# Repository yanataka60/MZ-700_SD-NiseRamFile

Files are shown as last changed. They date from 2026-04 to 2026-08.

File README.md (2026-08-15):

# MZ-700_SD+偽RAMFILE複合ボード

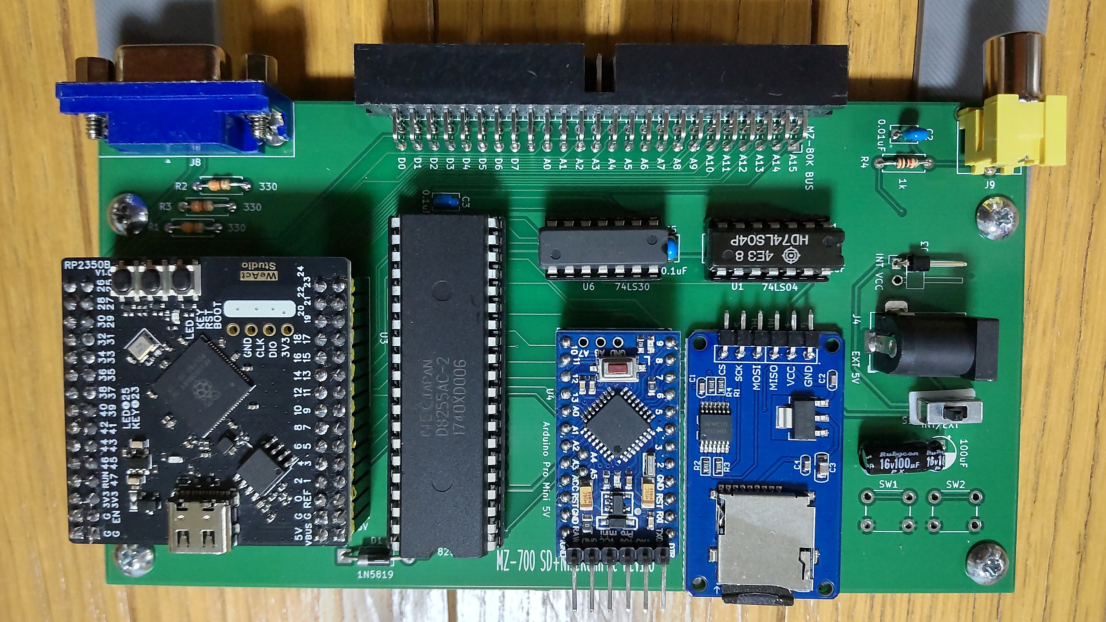
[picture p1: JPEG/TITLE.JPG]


　しっぽいいんちょさんが作られた「偽RAMFILE for MZ-1500」を元にしてMZ-700_SDを合体させたボードです。

　オマケとしてMZ-1500のサウンド機能を付加してMZ-1500用ゲームのサウンドも鳴るようにしてみました。あくまでオマケですので完全にMZ-1500と同等になるかは未検証です。

#### 2026.4.17 Rev1.2の回路中LPFのコンデンサの位置に誤りがありました。後述「Rev1.2回路の修正」によりコンデンサの位置を修正してください。

#### 2026.4.25 Rev1.5以降では回路・基板改善しています。Rev1.2基板の場合のみ、後述「Rev1.2回路の修正」によりコンデンサの位置を修正してください。

#### 2026.6.21 MZ-700_SD+偽RAMFILE複合ボードに電源が供給されている状態でUSB-Cケーブルを接続してはいけない問題に対してRev1.6基板ではすーぱーたーぼさんからご指摘いただいた対策を施しました。Rev1.2、Rev1.5基板でも通常の使用でMZ-700_SD+偽RAMFILE複合ボードに電源が供給されている状態でUSB-Cケーブルを接続することはありませんので通常使用においてRev1.2、Rev1.5基板でも問題ありません。

　以下の機能があります。

・MZ-700_SDの起動及びMZ-700_SDの機能

・EMM0からの起動(ただし、EMM0にHu-BASICの起動ディスクイメージがある場合のみ)

・EMM0エミュレータ(320KByte)

・漢字ROMボードエミュレータ

・MZ-700のテキスト出力をエミュレートしてVGA出力

・VGA出力される出力にMZ-1500相当のPCG機能、パレット機能

・VGA出力される出力にPCG-700相当のPCG機能

・MZ-1500相当のサウンドエミュレート(SN76489x2、8253)

・EXT-ROM領域(E800h～FFFFh)のRAM化(起動時にはF000h～FFFFhにMZ-700_SD用ROMの内容が自動的に書き込まれます。1Z-009B_LauncherをLOAD起動後であればEXT-ROMをファイル化したEXT-ROM.MZTをEXT-ROM領域にLOADが可能です)

MZ-700_SD: https://github.com/yanataka60/MZ-700_SD

　「偽RAMFILE for MZ-1500」にはMZ-1R12 SRAMメモリエミュレータの機能がありますが、MZ-700_SDの起動用に使用しているのでMZ-1R12 SRAMメモリエミュレータとしての機能は使用できません。

　なおこの基板は、しっぽいいんちょさんの「偽1500 for MZ-700」のnise1500.uf2を書き込めば「偽1500 for MZ-700」になります。

　「偽1500 for MZ-700」とはフラッシュROMの使い方が違いますのでuf2ファイルを書き込んだときはそれぞれの説明に従ったフラッシュROMへの書込みを行ってください。

偽1500 for MZ-700:https://github.com/shippoiincho/nise1500

### (2026.8.13追記)すねいるさんのBARYONに対応するためArduinoプログラムを更新しました。また、ROMプログラムも合わせて更新することで多段ロードにも対応します。

### 多段ロードの詳細についてはMZ-80K_SDの「BARYON対応」「多段ロード対応」を参照してください。

　BARYON対応:https://github.com/yanataka60/MZ80K_SD#baryon%E5%AF%BE%E5%BF%9C2026813

　多段ロード対応:https://github.com/yanataka60/MZ80K_SD#%E5%A4%9A%E6%AE%B5%E3%83%AD%E3%83%BC%E3%83%89%E5%AF%BE%E5%BF%9C2026813

　Arduinoプログラム、ROMプログラムともMZ-80K_SD用に更新したものがそのまま使えます。

### BARYON起動時にE800h以降にも書き込み動作を行うようです。MZ-80K_SD、MZ-700_SDでは問題ありませんが、MZ-700_SD+偽RAMFILE複合ボードではE800h以降もRAM扱いとしていたため、SDアクセスルーチンが破壊されてしまいます。

### 当面、E800h以降はROM扱いに変更しましたのでRP2350Bフォルダにあるniseramfile.uf2でRP2350Bマイコンボードを書き換えてください。

## 回路図
　KiCadフォルダ内のMZ-700_SD+NRF.pdfを参照してください。

[回路図](https://github.com/yanataka60/MZ-700_SD-NiseRamFile/blob/main/KiCad/MZ-700_SD%2BNRF.pdf)

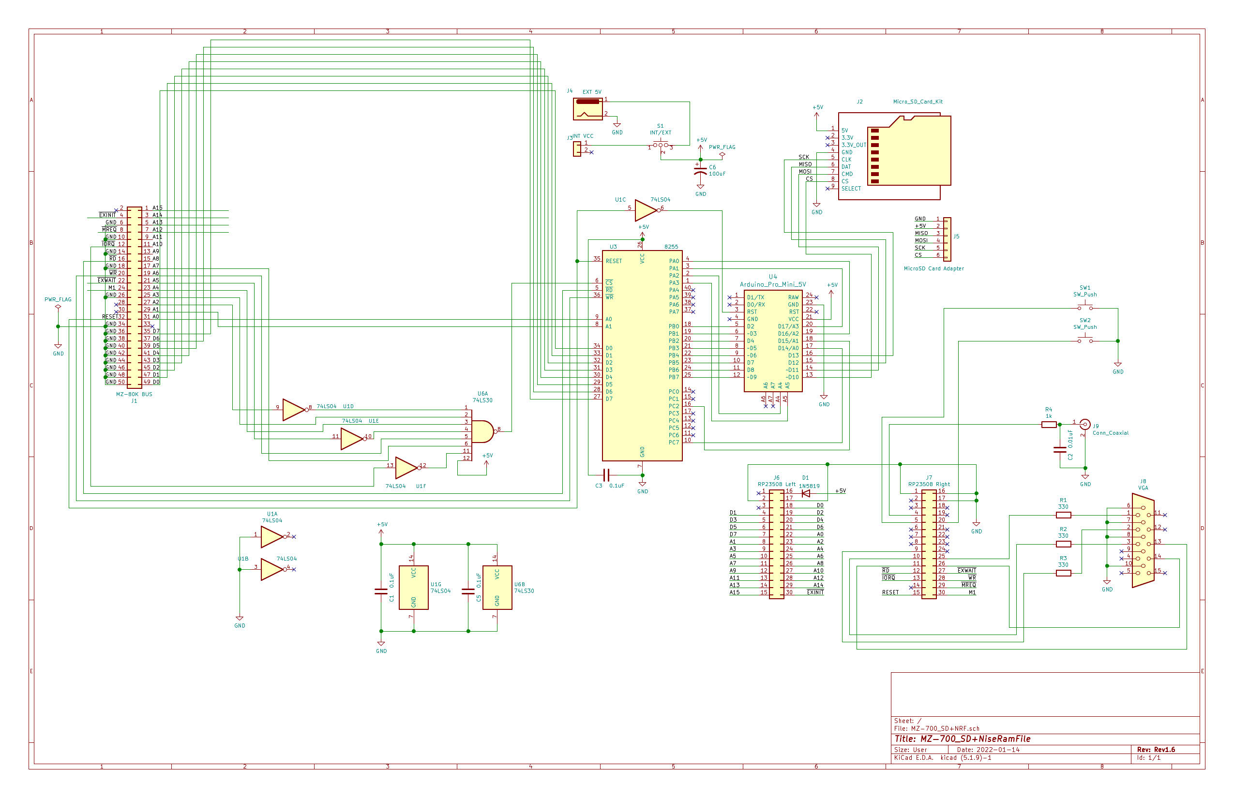
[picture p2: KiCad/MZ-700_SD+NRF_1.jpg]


|番号|品名|数量|備考|
| --- | --- | --- | --- |
||J2、J5のいずれか|||
|J2|Micro_SD_Card_Kit|1|秋月電子通商 AE-microSD-LLCNV (注2)|
|J5|MicroSD Card Adapter|1|Arduino等に使われる5V電源に対応したもの(注4)|
|J3|コネクタ 2Pin|1|ピンヘッダで代用するときはGNDと間違えないよう1Pinで5Vだけにしたほうが良い|
|J4|DCジャック|1||
|J6,J7|ピンソケット2x15Pin|2|RP2350Bマイコンボード用,秋月電子通商 FHU-2x42SGなど|
|J8|VGA用基板ソケット 3列15ピン|1|マルツ DJ-VGA14.5など (注1)|
|J9|RCAジャック|1|秋月電子通商 MJ-523など|
|S1|3Pスライドスイッチ|1|秋月電子通商 SS12D01G4など|
|U1|74LS04|1||
|U3|8255|1||
|U4|Arduino_Pro_Mini_5V|1|Atmega328版を使用 168版は不可。(注3)|
|U6|74LS30|1||
||RP2350Bボード(Raspberry Pi Pico 2)|1|Amazon WA00021 RP2350Bマイコンボードなど|
|C1,C3,C5|積層セラミックコンデンサ 0.1uF|3||
|C2|積層セラミックコンデンサ 0.01uF|1||
|C6|電解コンデンサ 16v100uF|1||
|D1|ダイオード 1N5819|1||
|R1-R3|カーボン抵抗 330Ω|3||
|R4|カーボン抵抗 1kΩ|1||
||ピンヘッダ|2Pin分|Arduino_Pro_MiniにはA4、A5用のピンヘッダが付いていないため別途調達が必要です 秋月電子通商 PH-1x40SGなど|
||ピンソケット(任意)|26Pin分|Arduino_Pro_Miniを取り外し可能としたい場合に調達します 秋月電子通商 FHU-1x42SGなど|

　　　注1)VGA用基板ソケットには、ピン間隔の異なるものがあるようです。マルツ DJ-VGA14.5ではないものを購入する場合はこちらで寸法を確認してください。

　　　https://www.marutsu.co.jp/contents/shop/marutsu/datasheet/DJ-VGA14.5.pdf

　　　注2)秋月電子通商　AE-microSD-LLCNVのJ1ジャンパはショートしてください。

　　　注3)Arduino Pro MiniはA4、A5ピンも使っています。

　　　注4)MicroSD Card Adapterを使う場合

　　　　　J6に取り付けます。

　MicroSD Card Adapterについているピンヘッダを除去してハンダ付けするのが一番確実ですが、J6の穴にMicroSD Card Adapterをぴったりと押しつけ、裏から多めにハンダを流し込むことでハンダ付けをする方法もあります。なお、この方法の時にはしっかりハンダ付けが出来たかテスターで導通を確認しておいた方が安心です。

　ハンダ付けに自信のない方はJ5の秋月電子通商　AE-microSD-LLCNVをお使いください。AE-microSD-LLCNVならパワーLED、アクセスLEDが付いています。

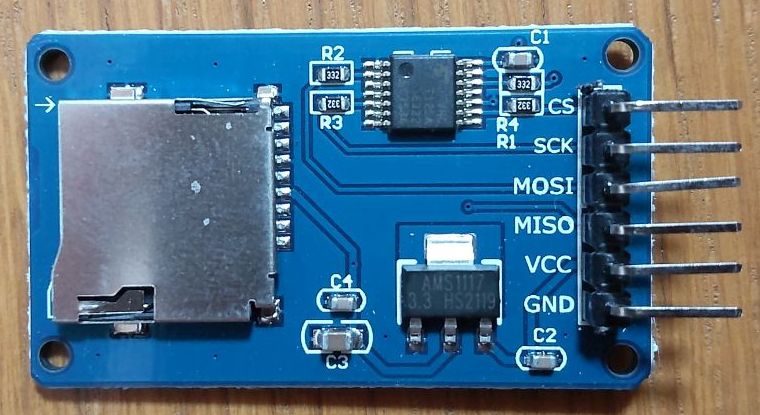
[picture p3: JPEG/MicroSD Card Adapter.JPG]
MicroSD Card Adapter1


## Rev1.2回路の修正(Rev1.2のみ、Rev1.5以降では修正しています)
　Rev1.2の回路に誤りがありました。LPF用コンデンサ(C2)を取り外し、0.01uFに変更の上、基板ハンダ面よりR4の出力側になるように取り付けてください。

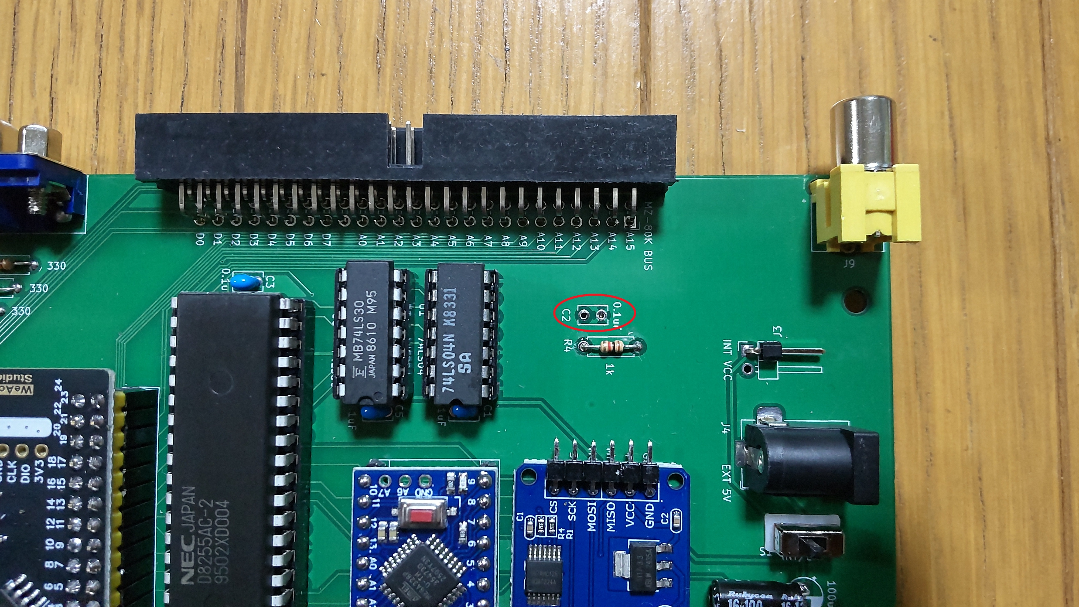
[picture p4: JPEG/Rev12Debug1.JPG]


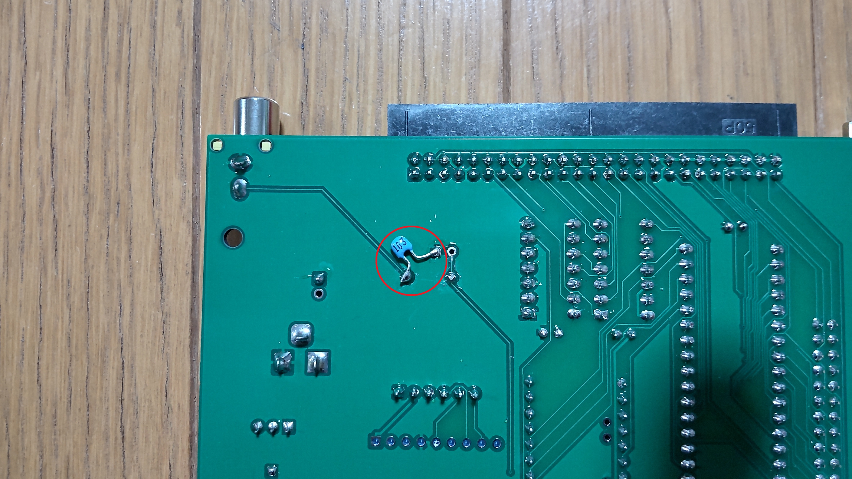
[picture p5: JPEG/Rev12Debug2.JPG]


## 偽RAMFILE for MZ-700の書込み
　RP2350Bフォルダにあるniseramfile.uf2をRP2350Bマイコンボードに書き込みます。

　RP2350BのBOOTボタンを押しながらUSB-Cケーブルを接続するとパソコンがUSBメディアとして認識しますのでniseramfile.uf2をドロップすると自動的に書き込まれます。

　書き込みが終了するとパソコンからはUSBとして見えなくなりますのでそうなったらケーブルを抜いて終了です。

### 書き込み(USB-Cケーブル接続)時の注意
#### Rev1.2基板、Rev1.5基板
　USB-Cケーブルを接続するときは、USB-C以外からMZ-700_SD+偽RAMFILE複合ボードに電源が供給されないようにしてください。

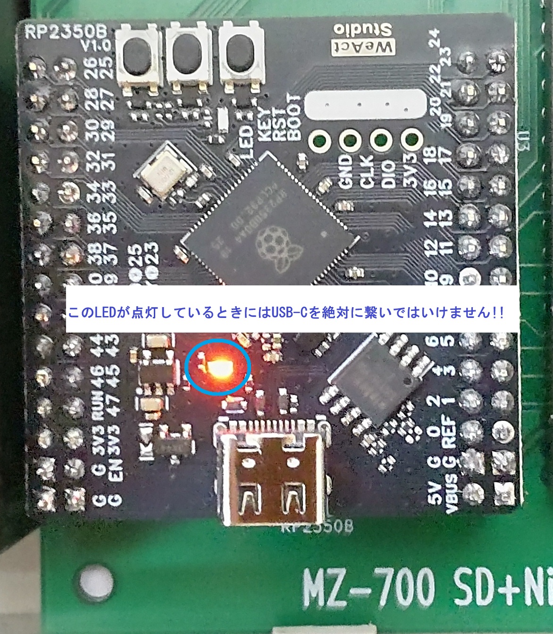
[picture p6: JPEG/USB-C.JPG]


　MZ-700内部から内部電源として供給しているならMZ-700の電源は必ず切っておく、ACアダプタから外部電源として供給しているなら電源ジャックから外しておいてください。

　また、書き込み終わったらUSB-Cは必ず外してください。

#### Rev1.6基板
　対策済みです。USB-Cケーブルを接続するときにUSB-C以外からMZ-700_SD+偽RAMFILE複合ボードに電源が供給されていても問題は無くなっていますが、書き込むときにはUSB-Cケーブル以外から電源が供給されていない状態で行う方が無難です。

## MZ-700_SD用ROMプログラムの書き込み
~~MZ-700_SD/EMMフォルダ内のFD_rom1.bin又はFD_rom.binをRP2350BのフラッシュROMへ書き込みます。~~

~~https://github.com/yanataka60/MZ-700_SD/blob/main/EMM/FD_rom.BIN~~

(2026.8.13)多段ロード対応に伴い、MZ-80K_SDに統合しました。MZ-80K_SD/Z80フォルダ内のFD_rom.BINを使ってください。

https://github.com/yanataka60/MZ80K_SD/blob/main/Z80/FD_rom.BIN

　書き込みにはpicotool.exeが必要となります。以下のウェブページ右側の「Releases」からダウンロードできます。

https://github.com/raspberrypi/pico-sdk-tools

```
picotool.exe load -v -x FD_rom1.bin  -t bin -o 0x10080000
```

　また、EMM0に起動可能な内容(HuBASIC起動イメージ)があればEMMからの起動が可能です。

　EMMの内容をチェックしていないのでEMMが起動可能な内容(HuBASIC起動イメージ)でなかった場合には暴走しますのでご注意ください。

　EMM0からの起動は、MONITORから「FDE0」コマンドで起動できます。

## FONTファイルの書込み
　VGA出力を有効とするためにはMZ-700のフォントをRP2350Bに書き込む必要があります。

　MZ-700はソフトウェア的にフォントを取り出すすべがありませんが、疑似的に作り出す又はソフトウェアで読み出せるMZ-1500のFONTを使うなどの方法があります。Webで検索して作成してください。

　書き込みはpicotoolを使います。

```
picotool.exe load -v -x font.rom  -t bin -o 0x1001f000
```

## Arduinoプログラム
　MZ-80K_SDを参照してください。

https://github.com/yanataka60/MZ80K_SD?tab=readme-ov-file#arduino%E3%83%97%E3%83%AD%E3%82%B0%E3%83%A9%E3%83%A0

## 拡張機能の使い方
### MZ-700_SD(MZ-80K_SD)の起動
　MZ-700_SD(MZ-80K_SD)の起動方法、使用方法と同じです。

MZ-700_SD:https://github.com/yanataka60/MZ-700_SD

MZ-80K_SD:https://github.com/yanataka60/MZ80K_SD

### EMM0エミュレータ
　320KByteのEMM0として機能します。バッテリーバックアップ機能はなく、電源断で内容は消失します。

　ただし、バックアップ用のSlotが32個用意されているので電源断前にSlotに退避しておくことが可能です。

　また、Slot0の内容は電源投入又はIPL RESETした時にEMM0に自動的にコピーされるのであたかもバッテリーバックアップされていたかのような使い方が出来ます。

　EMMとSlotとのやり取りはI/Oポートから指示します。

#### SlotxxからEMM0への復帰
|アドレス|R/W|説明|
| --- | --- | --- |
|8Ch|W|指定したSlot番号(0～31)のSlotの内容をEMM0に復帰|

#### EMM0からSlotxxへの退避
|アドレス|R/W|説明|
| --- | --- | --- |
|8Dh|W|指定したSlot番号(0～31)のSlotへEMM0の内容を退避|

HuBASICからは以下のようになります。

```
OUT &H8C,0
```

```
OUT &H8D,0
```

　「EMM0」に起動可能なMZ-700用HuBASICが存在している場合、コマンド「FDE0」を実行することで「EMM0」のMZ-700用HuBASICから起動可能です。

　なお、EMMの00000番地が「01h」でなければEMMからの起動はせずにコマンド待ちに戻りますが、00000番地以降に異常があってもチェックはしていないので最悪暴走します。

　MZ-700用HuBASICは、テープ版しかなくそのままではEMMにHuBASICの起動イメージを作成することが出来ません。

　BouKiCHiさんのHuDiskなどを使いMZ-700用HuBASICの起動ディスクイメージを作成したうえでEMMMENUのEMMLOADでEMMに書き込む必要があります。

　EMMイメージを登録する場合はpicotoolから以下のようにします。

```
picotool.exe load -v -x EMM_image.bin  -t bin -o 0x10280000
```

### 漢字・辞書ROM MZ-1R13
　漢字・辞書ROM MZ-1R13から抽出したデータを登録します。

　抽出にはGET1R13を使いました。

http://fukui.s17.xrea.com/retro/mz2080b/mzgetkrom.html

　出来上がったファイルをpicotoolで登録します。

```
picotool.exe load -v -x MZ_1R13_DIC.ROM -t bin -o 0x10040000
```

```
picotool.exe load -v -x MZ_1R13.ROM  -t bin -o 0x10020000
```

## MZ-80K用ゲーム(アプリケーション)の実行
　FDL、FDコマンドでLOAD実行が可能です。アプリケーション内でのLOAD、SAVEには本体内ROMの書き換え、もしくはアプリケーションの書き換えが必要です。

　また、キーボードの違いによりそのまま動かないことがあります。

　詳しくは、MZ-80K_SDを参照してください。

https://github.com/yanataka60/MZ80K_SD

## MZ-700用ゲーム(アプリケーション)の実行
　FDL、FDコマンドでLOAD実行が可能です。アプリケーション内でのLOAD、SAVEにはアプリケーションを対応させる必要がある場合があります。

　詳しくは、MZ-80K_SDを参照してください。

https://github.com/yanataka60/MZ80K_SD

## MZ-1500用ゲーム(アプリケーション)の実行
　MZ-1500用ゲーム(アプリケーション)が動作するかもしれないのはあくまでもオマケです。動作したらラッキーぐらいでお願いします。

　なお、QD用ソフトは、事前にMZTファイル化しておいてください。

　また、アプリケーション内でLOAD、SAVEするにはMZ-1500_SDでアプリケーション内でのLOAD、SAVEに対応している必要があります。

　次の段階で試してみてください。

#### ①FDL、FDコマンドでLOAD実行。
　①で動いたもの

　　いぬふとさんのゲーム、PACKMAN、ICE BLOCK

#### ②多段LOADの場合は、FDL、FDコマンドでLOAD実行(PCG定義)。リセットして２段目をFDL、FDコマンドでLOAD実行(ゲーム本体)。
　②で動いたもの

　　DOORDOORmk2、FLAPPY、RALLY-X、ヴォルガード、DIGDUG、MAPPY、GALAGA、ドルアーガの塔(遊べますが外壁PCG定義が変です)

#### ③FDL、FDコマンドで1Z-009B_LauncherをLOAD実行し、1Z-009B_LauncherからFDL、FDコマンドでLOAD実行。
　③で動いたもの

　　サンダーフォース、BASIC MZ-5Z001(もしかしたら④の方が良いのかも)

#### ④FDL、FDコマンドで1Z-009B_LauncherをLOAD実行後、1Z-009B_LauncherからMZ-1500用EXT-ROM(E800h～FFFFh、実行アドレスE800h)をLOAD実行、MキーでMONITOR 9Z-502Mを起動したら「J0000」を実行して1Z-009B_Launcherに戻り、目的のアプリケーションをFDL、FDコマンドでLOAD実行。
　④で動いたもの

　　今のところ④が必要となったものには出会っていません。もしかしたらBASIC MZ-5Z001の機能のうち、EXT-ROMを必要とするものがあるかもしれません。

　　(2026.8.13追記)当面、E800h以降はROM扱いに変更しましたので④は使えなくなります。

### 1Z-009B_Launcherの作り方
　1Z-009B_Launcherフォルダにある1Z-009B_SD.mzt(2630Byte)の後ろにMZ-1500実機から抽出した1Z-009B MONITOR(0000h～0FFFh)をバイナリエディタなどで連結して保存してください。

　6627Byteのファイルになります。

　(2026.8.15追記)1Z-009B_Launcherも多段ロード対応にさせました。ただし今のところ1Z-009B_Launcherを使うのは③の場合のみですので使う場面はありません。

### MZ-1500用EXT-ROMファイルの作り方

(2026.8.15追記)E800h以降をROM扱いに変更しましたのでLOAD出来なくなりました。

　MZ-1500実機からEXT-ROM(E800h～FFFFh)までを抽出してバイナリファイルとしたうえでヘッダを付加してmztファイルとしてください。

　この時、実行アドレスをE800hとしておきます。

### MZ-700_SD+偽RAMFILE複合ボード対応BASIC MZ-5Z001
　前述「MZ-1500用ゲーム(アプリケーション)の実行」の③又は④でBASIC MZ-5Z001は実行可能ですが、SDを使用するにはSD用パッチあてが必要です。

　MZ-1500_SDとMZ-700_SDではArudinoをコントロールする8255のI/Oアドレスに違いがあり、MZ-1500_SD対応パッチを当てたBASIC MZ-5Z001はそのままでは使えないのでバイナリエディタで以下の修正を行ってください。

　「BASIC 1Z-5Z001-SD.MZT」(AUTORUN未対応版 42581Byte)
|MZTアドレス|修正前|修正後|
| --- | --- | --- |
|A30F|A3|DB|
|A313|A0|D8|
|A315|A2|DA|
|A31B|A1|D9|
|A320|A3|DB|
|A327|A3|DB|
|A33C|A0|D8|
|A340|A3|DB|
|A347|A3|DB|
|A34D|A2|DA|
|A354|A2|DA|

　「BASIC 1Z-5Z001-SD-AUTORUN.MZT」(AUTORUN対応版 42592Byte)
|MZTアドレス|修正前|修正後|
| --- | --- | --- |
|A31A|A3|DB|
|A31E|A0|D8|
|A320|A2|DA|
|A326|A1|D9|
|A32B|A3|DB|
|A332|A3|DB|
|A347|A0|D8|
|A34B|A3|DB|
|A352|A3|DB|
|A358|A2|DA|
|A35F|A2|DA|

## 専用トレイとカバー
　専用トレイとカバーを作ってみました。

　STLフォルダにあるSTLファイルを使ってください。

　トレイはCMTユニットを引っ掛ける手前のツメの下に潜り込ませるように入れます。

　カバーは手前からかぶせてツメに引っ掛けます。

　カバーを外すときは背面からトレイごと持ち上げるようにすると外れます。

　カバー内は、RP2350Bがギリギリ入る高さ16mmほどです。Arduino、SDカードユニットにソケットを使うときはその高さに収まる背の低いタイプを使ってください。

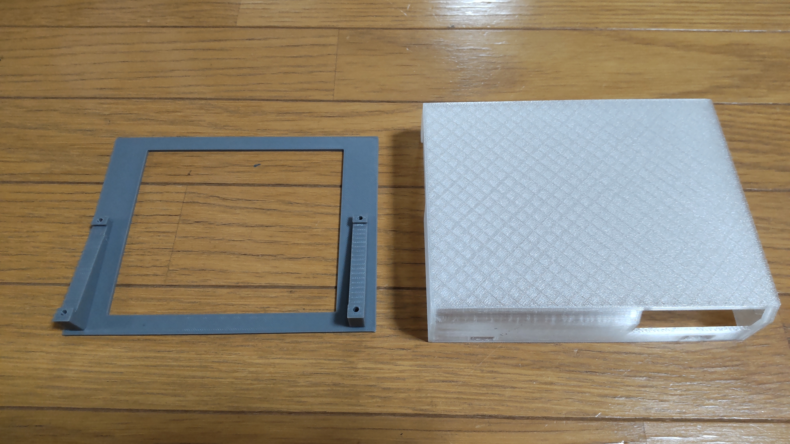
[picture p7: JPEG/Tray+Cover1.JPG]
Tray+Cover1


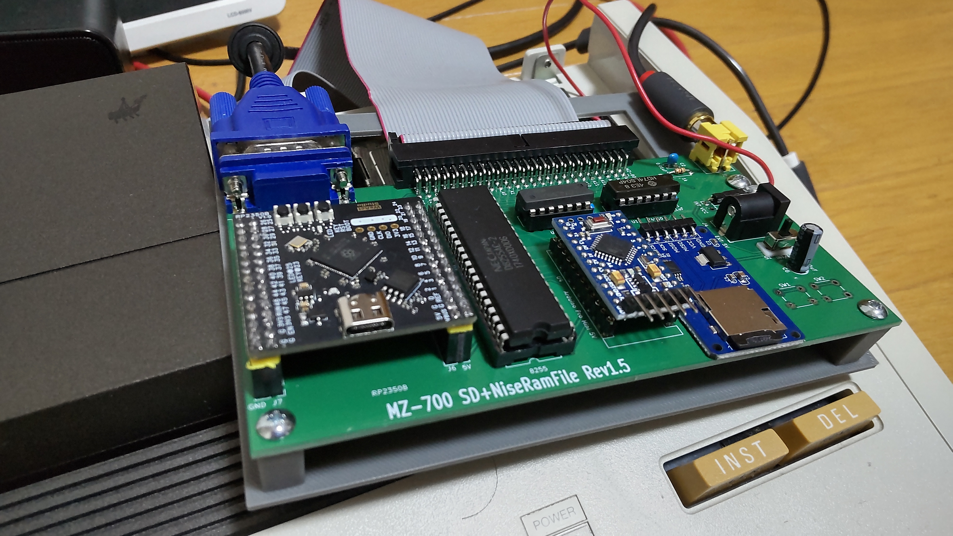
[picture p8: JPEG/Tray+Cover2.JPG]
Tray+Cover2


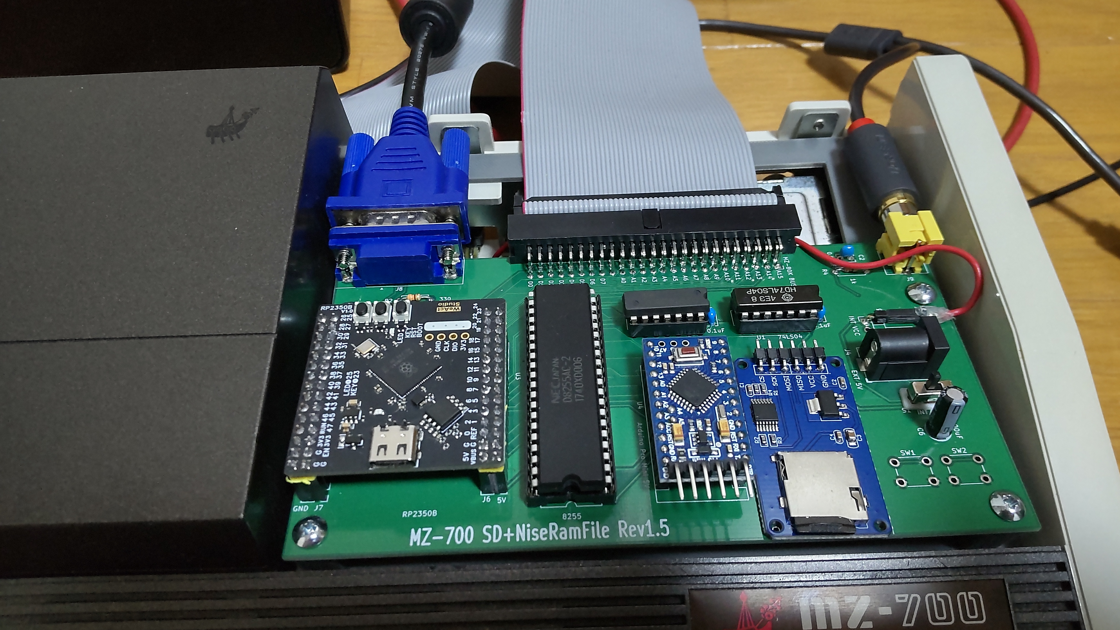
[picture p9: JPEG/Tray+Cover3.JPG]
Tray+Cover3


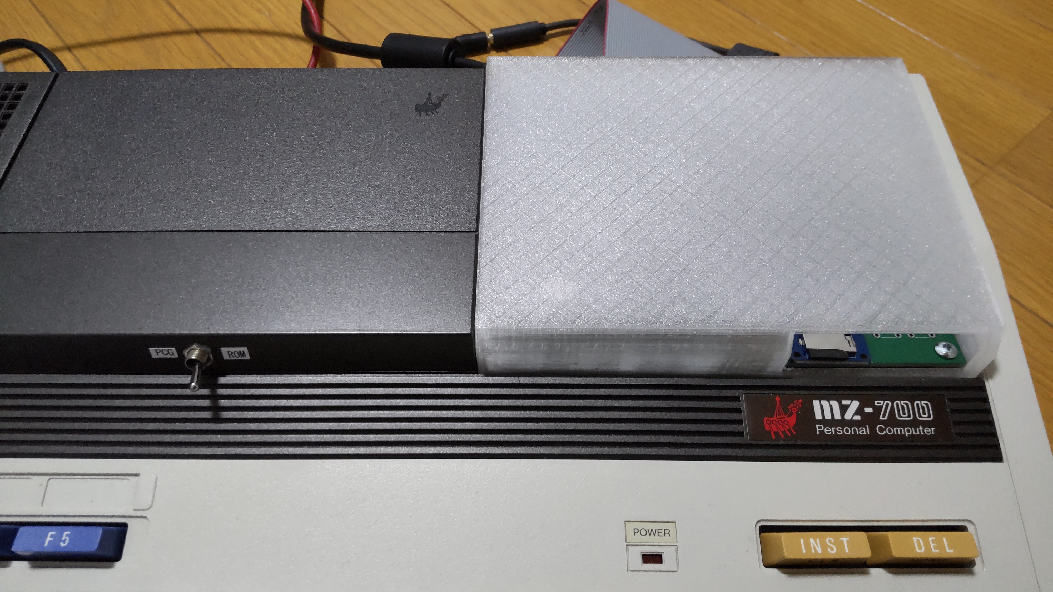
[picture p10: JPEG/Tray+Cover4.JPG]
Tray+Cover4


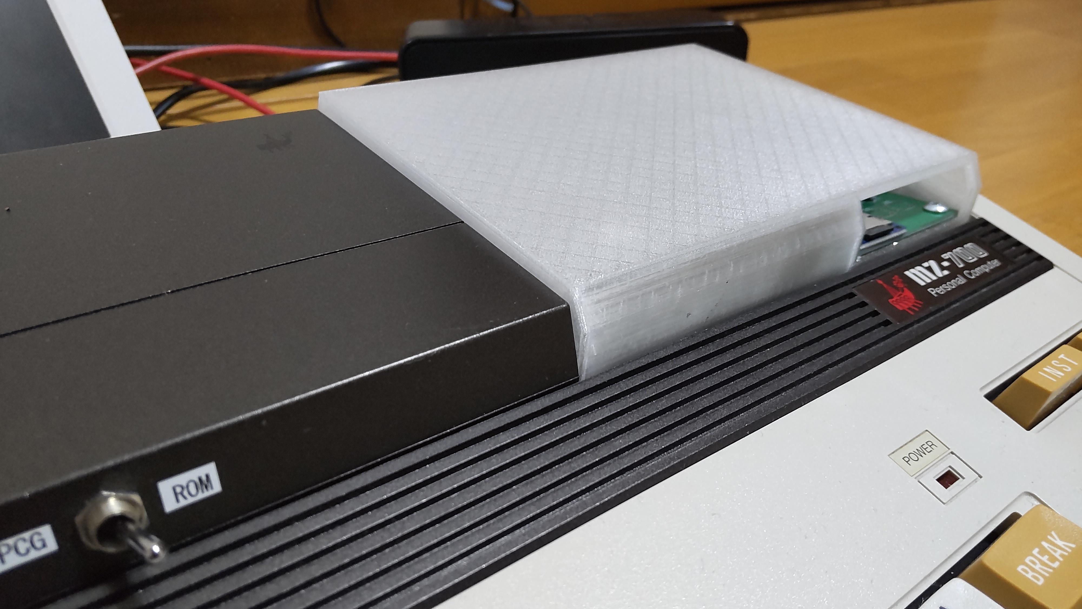
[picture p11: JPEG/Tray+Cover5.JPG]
Tray+Cover5


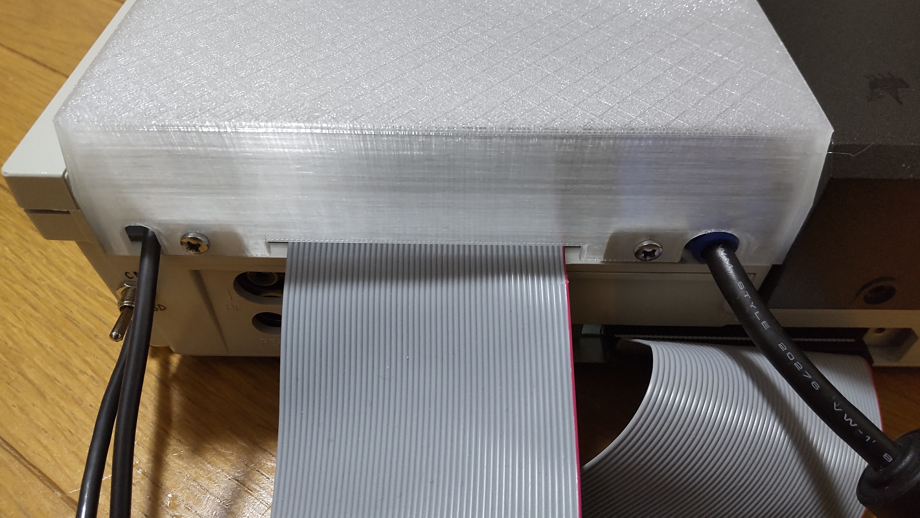
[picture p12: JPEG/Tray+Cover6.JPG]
Tray+Cover6


## 開発環境、使用ライブラリなど
　開発環境は、Visual Studio Codeです。

　VGAライブラリは以下を使用しています。

- [VGA ライブラリ(一部改変)](https://github.com/vha3/Hunter-Adams-RP2040-Demos/tree/master/VGA_Graphics)

## 謝辞
　素晴らしい拡張モジュールを開発し、自由に改変・公開を快く承諾してくださったしっぽいいんちょさん、ありがとうございました。

## 追記
2026.4.17 Rev1.2回路でLPFのコンデンサの位置に誤りがありました。すーぱーたーぼさん、ご指摘ありがとうございます。

2026.4.18 書き込み(USB-Cケーブル接続)時の注意を追記しました。

2026.4.25 Rev1.5を公開しました。

2026.4.30 トレイとカバーのSTLファイルを追加しました。
          MZ-700_SD+偽RAMFILE複合ボード対応BASIC MZ-5Z001にするための修正点を追記。

2026.6.21 MZ-700_SD+偽RAMFILE複合ボードに電源が供給されている状態でUSB-Cケーブルを接続してはいけない問題に対してすーぱーたーぼさんからご指摘いただいた対策を施しました。

2026.8.13 BARYONに対応しました。retrogamer128さんの要望により多段ロードに対応しました。

2026.8.15 1Z-009B_Launcherも多段ロード対応としました。

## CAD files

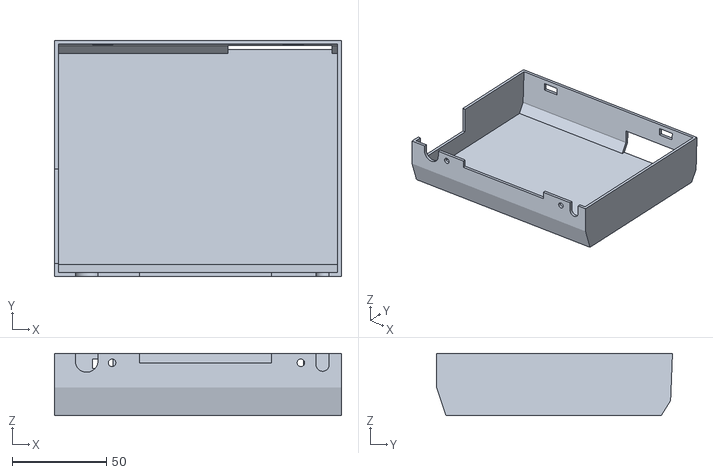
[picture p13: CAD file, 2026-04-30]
STL/MZ-700_SD+Nise_Cover.stl
152.0 x 125.0 x 33.0

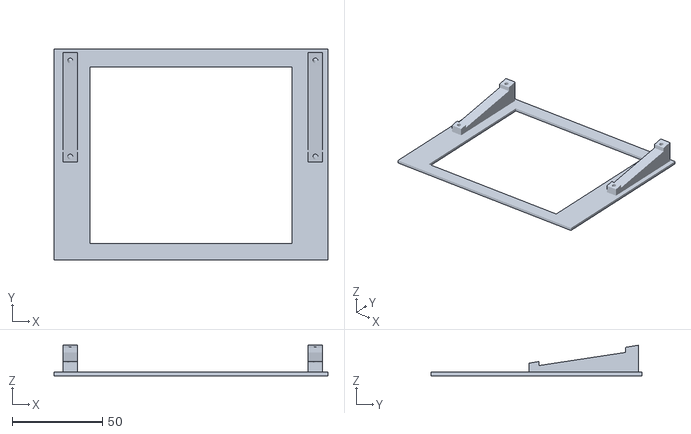
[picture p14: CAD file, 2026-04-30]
STL/MZ-700_SD+Nise_Tray.stl
152.0 x 117.0 x 17.0

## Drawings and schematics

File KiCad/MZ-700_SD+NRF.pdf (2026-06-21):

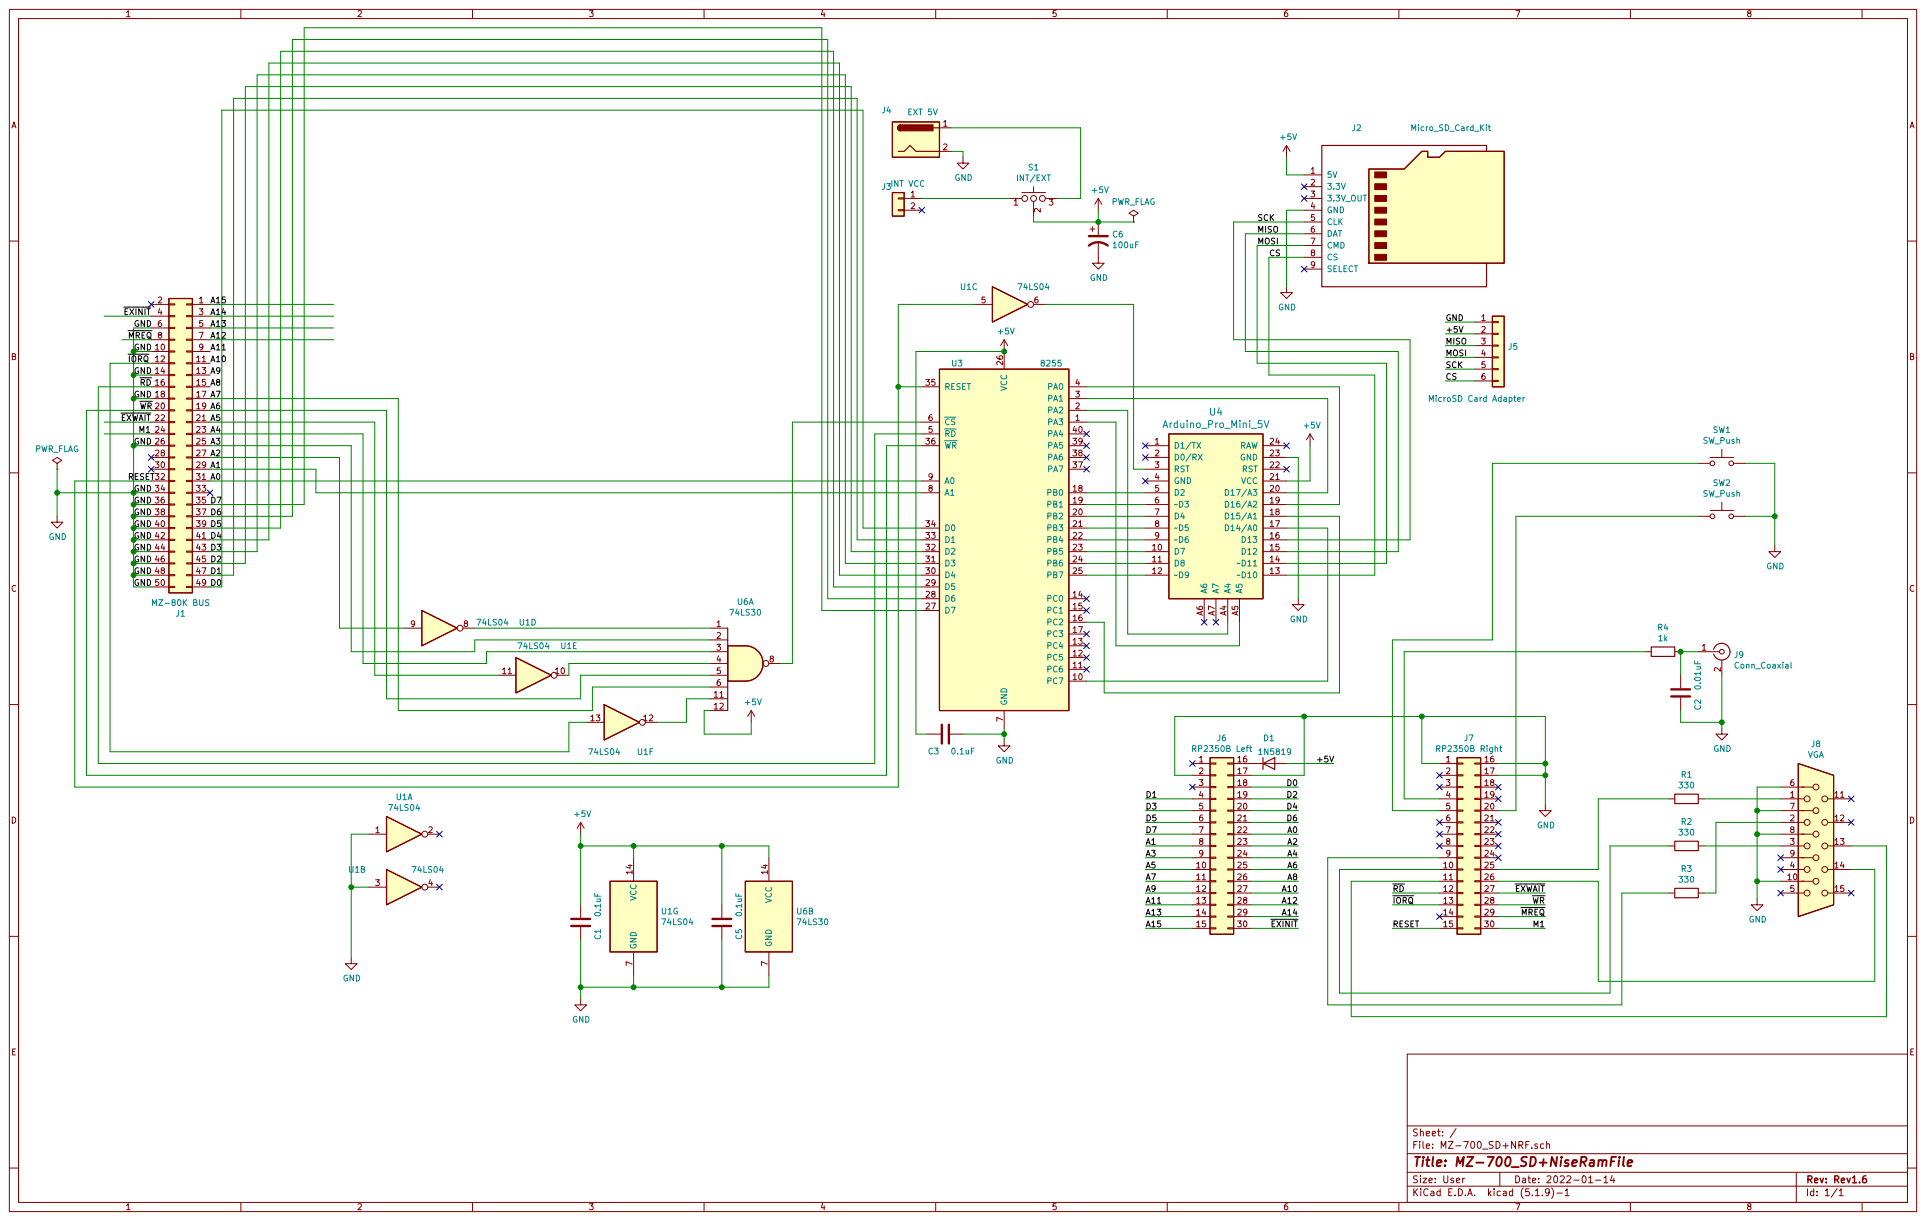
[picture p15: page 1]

EXINIT GND GND GND GND GND GND

EXWAIT GND GND GND GND MREQ

38 | 37
40 | 39
42 | 41
44 | 43
46 | 45
48 | 47
GND 50 | 49

File: MZ-700_SD+NRF.sch Sheet: /
Id: 1/1 Title: MZ-700_SD+NiseRamFile

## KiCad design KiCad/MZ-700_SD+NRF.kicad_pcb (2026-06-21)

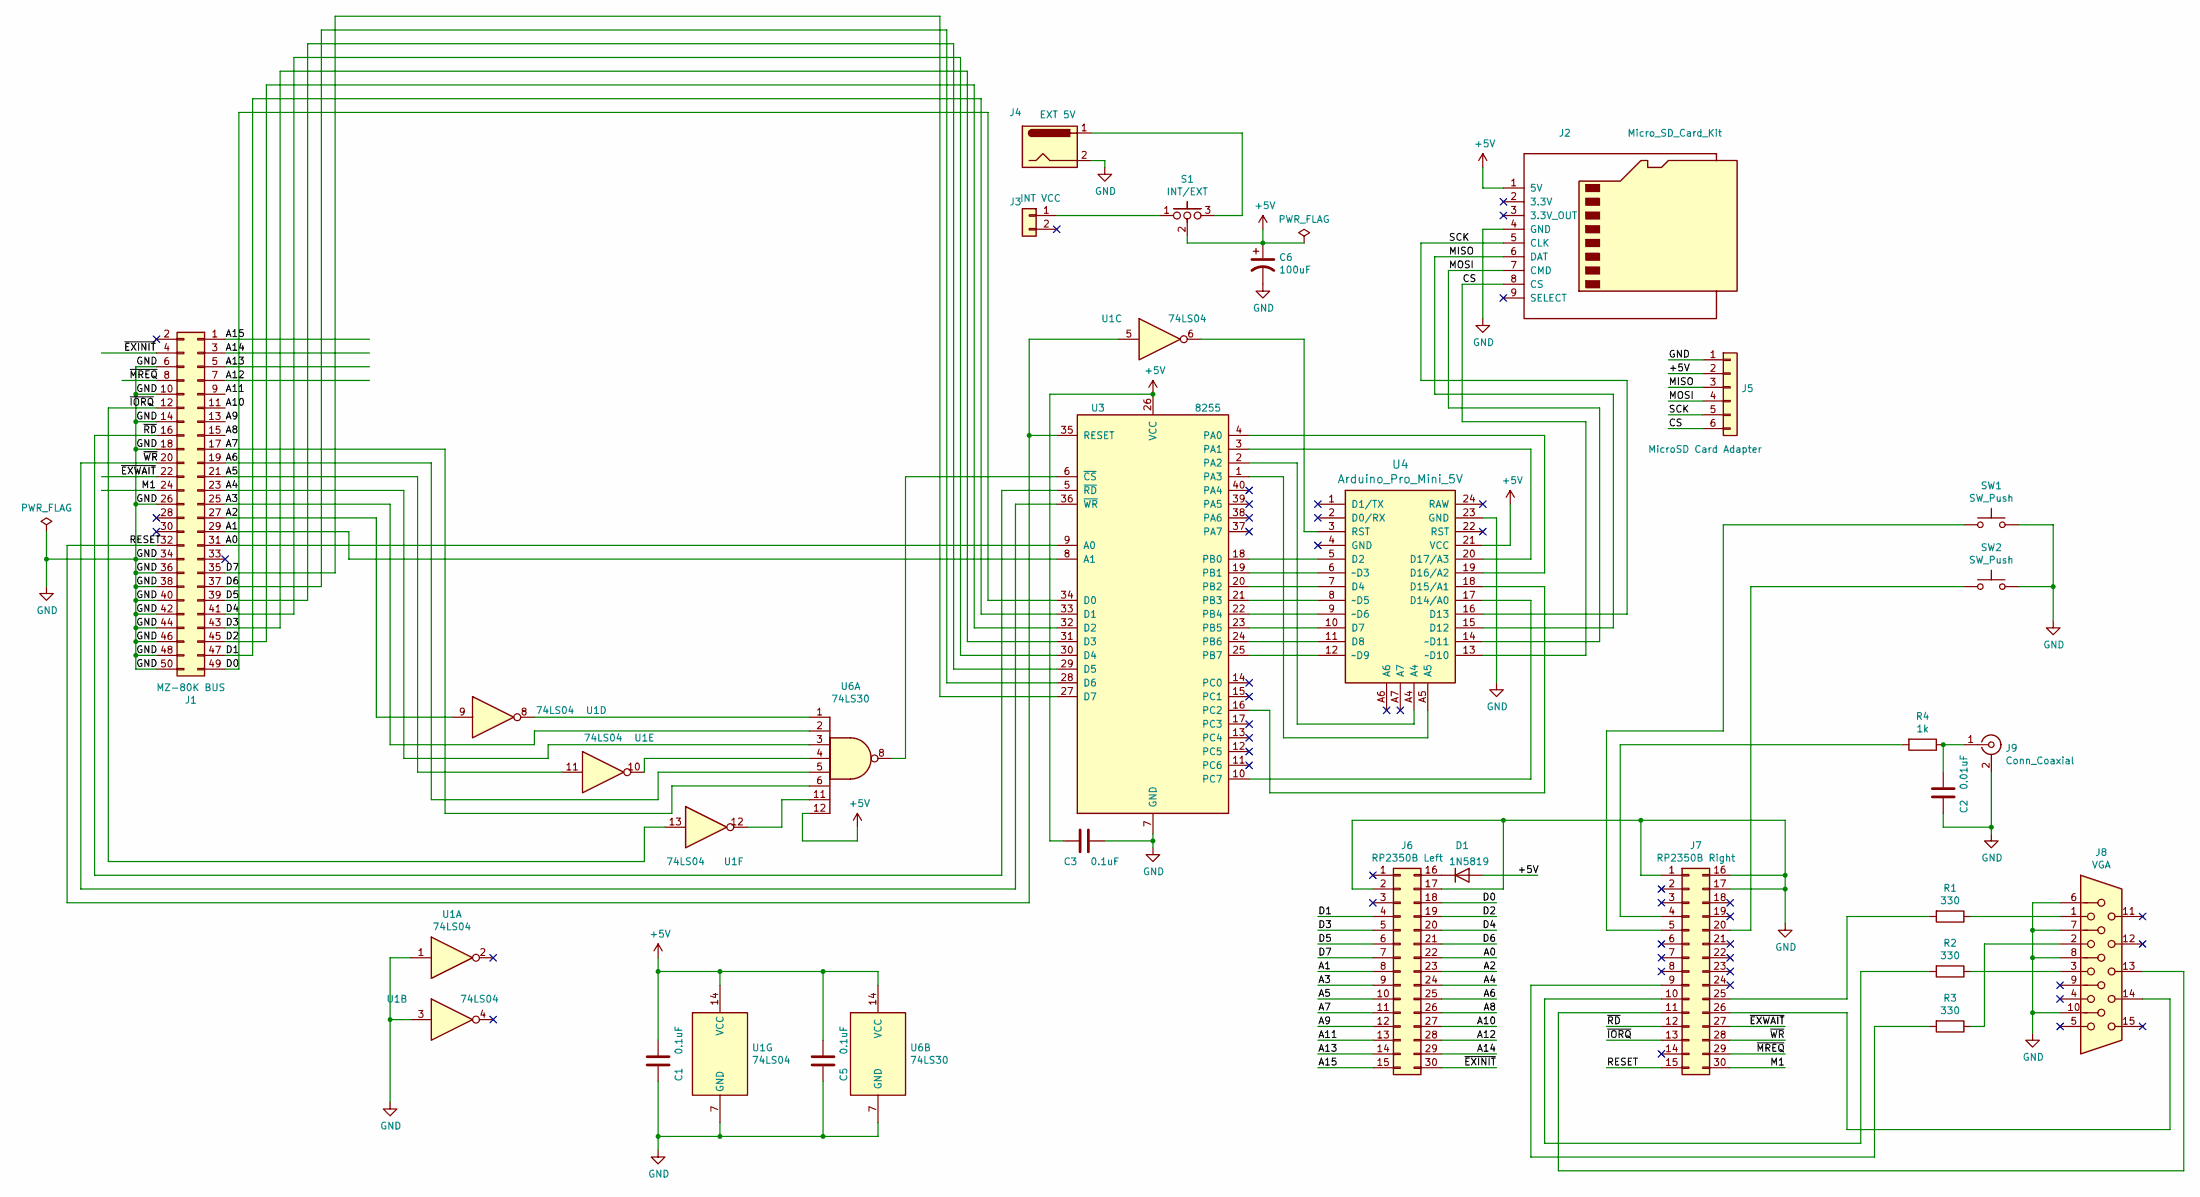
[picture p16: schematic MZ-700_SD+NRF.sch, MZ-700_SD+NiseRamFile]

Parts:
C1, C3, C5: 0.1uF; C_Rect_L4.0mm_W2.5mm_P2.50mm
C2: 0.01uF; C_Rect_L4.0mm_W2.5mm_P2.50mm
C6: 100uF; CP_Radial_D5.0mm_P2.50mm
D1: 1N5819; D_DO-41_SOD81_P10.16mm_Horizontal
J1: MZ-80K BUS; PinSocket_2x25_P2.54mm_Horizontal
J2: Micro_SD_Card_Kit; AE-microSD-LLCNV
J3: INT VCC; PinHeader_1x02_P2.54mm_Horizontal
J4: EXT 5V; BarrelJack_Horizontal
J5: MicroSD Card Adapter; PinSocket_1x06_P2.54mm_Vertical
J6: RP2350B Left; PinHeader_2x15_P2.54mm_Vertical
J7: RP2350B Right; PinHeader_2x15_P2.54mm_Vertical
J8: VGA; DSUB-15-HD_Female_Horizontal_P2.29x1.98mm_EdgePinOffset3.03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
J9: Conn_Coaxial; RCAConAE
R1, R2, R3: 330; R_Axial_DIN0207_L6.3mm_D2.5mm_P7.62mm_Horizontal
R4: 1k; R_Axial_DIN0207_L6.3mm_D2.5mm_P7.62mm_Horizontal
S1: INT/EXT; PinHeader_1x03_P2.54mm_Vertical
SW1, SW2: SW_Push; SW_PUSH_6mm_H4.3mm
U1: 74LS04; DIP-14_W7.62mm_LongPads
U3: 8255; DIP-40_W15.24mm_LongPads
U4: Arduino_Pro_Mini_5V; Arduino_Pro_Mini
U6: 74LS30; DIP-14_W7.62mm_LongPads

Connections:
+5V: C1.2, C3.1, C5.2, C6.1, D1.2 (A), J2.1 (5V), J5.2, S1.2, U1.14 (VCC), U3.26 (VCC), U4.21 (VCC), U6.12, U6.14 (VCC)
/A0: J1.31, J6.22, U3.9 (A0)
/A1: J1.29, J6.8, U3.8 (A1)
/A2: J1.27, J6.23, U1.9
/A3: J1.25, J6.9, U6.2
/A4: J1.23, J6.24, U6.3
/A5: J1.21, J6.10, U1.11
/A6: J1.19, J6.25, U6.5
/A7: J1.17, J6.11, U6.6
/A8: J1.15, J6.26
/A9: J1.13, J6.12
/A10: J1.11, J6.27
/A11: J1.9, J6.13
/A12: J1.7, J6.28
/A13: J1.5, J6.14
/A14: J1.3, J6.29
/A15: J1.1, J6.15
/CS: J2.8 (CS), J5.6, U4.13 (~~D10)
/D0: J1.49, J6.18, U3.34 (D0)
/D1: J1.47, J6.4, U3.33 (D1)
/D2: J1.45, J6.19, U3.32 (D2)
/D3: J1.43, J6.5, U3.31 (D3)
/D4: J1.41, J6.20, U3.30 (D4)
/D5: J1.39, J6.6, U3.29 (D5)
/D6: J1.37, J6.21, U3.28 (D6)
/D7: J1.35, J6.7, U3.27 (D7)
/M1: J1.24, J7.30
/MISO: J2.6 (DAT), J5.3, U4.15 (D12)
/MOSI: J2.7 (CMD), J5.4, U4.14 (~~D11)
/RESET: J1.32, J7.15, U1.5, U3.35 (RESET)
/SCK: J2.5 (CLK), J5.5, U4.16 (D13)
/~EXINIT: J1.4, J6.30
/~EXWAIT: J1.22, J7.27
/~IORQ: J1.12, J7.13, U1.13
/~MREQ: J1.8, J7.29
/~RD: J1.16, J7.12, U3.5 (~RD~)
/~WR: J1.20, J7.28, U3.36 (~WR~)
GND: C1.1, C2.1, C3.2, C5.1, C6.2, J1.6, J1.10, J1.14, J1.18, J1.26, J1.34, J1.36, J1.38, J1.40, J1.42, J1.44, J1.46, J1.48, J1.50, J2.4 (GND), J4.2, J5.1, J6.2, J6.17, J7.1, J7.16, J7.17, J8.6, J8.7, J8.8, J8.10, J9.2 (Ext), SW1.2, SW2.2, U1.1, U1.3, U1.7 (GND), U3.7 (GND), U4.23 (GND), U6.7 (GND)
unnamed: C2.2, J9.1 (In), R4.1
unnamed: D1.1 (K), J6.16
unnamed: J3.1, S1.1
unnamed: J4.1, S1.3
unnamed: J7.4, R4.2
unnamed: J7.5, SW1.1
unnamed: J7.9, R3.2
unnamed: J7.10, R2.2
unnamed: J7.11, J8.13
unnamed: J7.20, SW2.1
unnamed: J7.25, R1.2
unnamed: J7.26, J8.14
unnamed: J8.1, R1.1
unnamed: J8.2, R3.1
unnamed: J8.3, R2.1
unnamed: U1.6, U4.3 (RST)
unnamed: U1.8, U6.1
unnamed: U1.10, U6.4
unnamed: U1.12, U6.11
unnamed: U3.1 (PA3), U4.A5
unnamed: U3.2 (PA2), U4.A4
unnamed: U3.3 (PA1), U4.20 (D17/A3)
unnamed: U3.4 (PA0), U4.19 (D16/A2)
unnamed: U3.6 (~CS~), U6.8
unnamed: U3.10 (PC7), U4.17 (D14/A0)
unnamed: U3.16 (PC2), U4.18 (D15/A1)
unnamed: U3.18 (PB0), U4.5 (D2)
unnamed: U3.19 (PB1), U4.6 (~~D3)
unnamed: U3.20 (PB2), U4.7 (D4)
unnamed: U3.21 (PB3), U4.8 (~~D5)
unnamed: U3.22 (PB4), U4.9 (~~D6)
unnamed: U3.23 (PB5), U4.10 (D7)
unnamed: U3.24 (PB6), U4.11 (D8)
unnamed: U3.25 (PB7), U4.12 (~~D9)

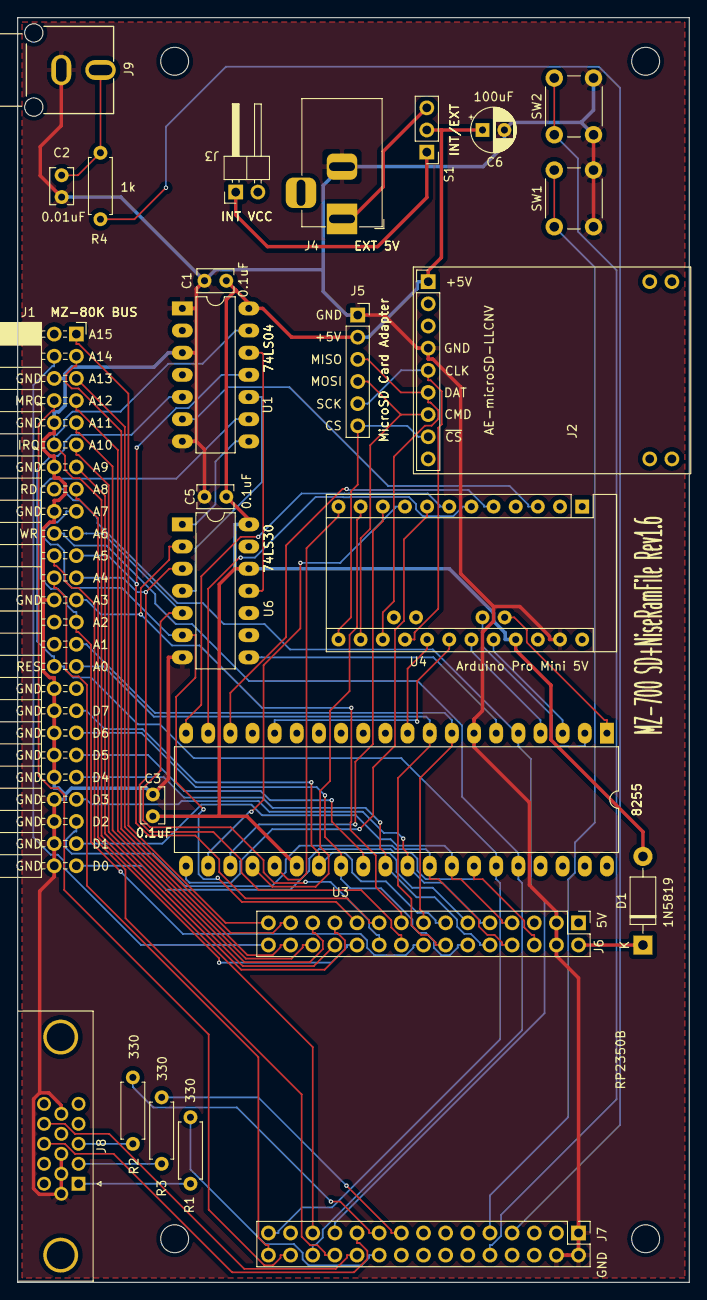
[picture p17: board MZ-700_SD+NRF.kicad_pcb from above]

Board: 2 copper layers, 77.0 x 145.0 mm, 30 parts (0 on the bottom side), 72 nets.

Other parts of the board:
MH1, MH2, MH3, MH4: MountingHole_3.2mm_M3

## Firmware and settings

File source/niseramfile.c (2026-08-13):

//  MZ-1500 Multi-function RAMFILE card 'Niseramfile'
//
//  MZ-1R12: RAM Memory (NO Battery backup)
//  MZ-1R18: RAMFILE
//  MZ-1R23: Kanji ROM
//  MZ-1R24: Jisho ROM
//  PIO-3034: EMM

//  MZ-1500 extention slot
//  GP0-7:  D0-7
//  GP8-23: A0-15
//  GP24: EXINT
//  GP25: RESET -> Interrupt
//  GP26: M1
//  GP28: MERQ
//  GP29: IORQ
//  GP30: WR
//  GP31: RD
//  GP32: EXWAIT

#define FLASH_INTERVAL 300      // 5sec

#include <stdio.h>
#include <stdlib.h>
#include <string.h>

#include "pico/stdlib.h"
#include "pico/multicore.h"
#include "pico/sync.h"
#include "hardware/pio.h"
#include "hardware/clocks.h"
#include "hardware/timer.h"
#include "hardware/uart.h"
#include "hardware/flash.h"
#include "hardware/sync.h"
#include "hardware/vreg.h"

#include "vga16_graphics.h"

#include "misc.h"

// ======================================================
// SN76489 Emulator
// ======================================================

#define SOUND_PIN 47
#define CLOCK_SN 3546895u
#define SAMPLE_RATE 44100

uint32_t pwm_slice_num;

typedef struct {
    uint16_t tone[3];
    uint8_t volume[4];
    uint8_t latched;

    uint32_t phase[4];
    uint32_t step[4];
    uint8_t output[4];

    uint16_t lfsr;
    uint8_t noise_mode;
    uint8_t noise_freq;

    int32_t dc;
    int32_t lp1;
    int32_t lp2;
} SN76489;

SN76489 sn_l, sn_r;

static const uint16_t vol_table[16] = {
    32767,26028,20675,16422,
    13045,10362,8231,6538,
    5197,4125,3277,2603,
    2067,1642,1304,0
};

// ======================================================
// i8253 PIT Emulator
// ======================================================

#define I8253CLOCK 894000 // NTSC

volatile uint8_t i8253[3];
volatile uint8_t i8253_access[3];
volatile uint16_t i8253_preload[3];
volatile uint16_t i8253_counter[3];
volatile uint8_t i8253_pending[3];
volatile uint16_t i8253_latch[3];
volatile uint32_t i8253_latch_flag=0;
volatile uint32_t i8253_enable_irq=0;

volatile uint32_t beep_flag=0;
volatile uint32_t beep_mute=0;

volatile uint8_t memioport[16];
volatile uint8_t pioa[4];
volatile uint8_t pioa_data;
volatile uint32_t pioa_enable_irq;
static repeating_timer_t sound_timer;

// PIO 状態保持（モード3用）
static uint8_t pioa_next_mask = 0;
static uint8_t pioa_next_iocontrol = 0;

static inline int32_t i8253_tick(void)
{
    uint16_t timer_diffs;
    uint32_t beep_on=0;
    uint32_t beep_volume=0;

    if(memioport[8]&1) {
        timer_diffs = I8253CLOCK / SAMPLE_RATE;

        if(timer_diffs < i8253_counter[0]) {
            i8253_counter[0] -= timer_diffs;
            if(memioport[2]&1) {
                beep_on = 1;
                switch(i8253[0] & 0x0E) {
                    case 0x06: // mode 3
                        beep_volume = (i8253_counter[0] > (i8253_preload[0]/2)) ? 255 : 0;
                        break;
                    case 0x00: // mode 0
                        beep_volume = 0;
                        break;
                    case 0x0A: // mode 5
                        beep_volume = 255;
                        break;
                }
            }
        } else {
            i8253_counter[0] = i8253_counter[0] + (i8253_preload[0] - timer_diffs);
            // タイマ割り込み (チャンネル0 → PIO ビット4)
            if((pioa[2] & 0x80) && ((pioa[3] & 0x10) == 0)) {
                pioa_enable_irq = 1;
                pioa_data |= 0x10;
            }
        }
    } else {
        if(memioport[2]&1) {
            beep_on = 1;
            beep_volume = 255;
        }
    }

    if(beep_mute) return 0;
    return beep_on ? (int32_t)beep_volume : 0;
}

static inline void sn_reset(SN76489 *sn)
{
    memset(sn, 0, sizeof(SN76489));
    for(int i=0;i<4;i++) sn->volume[i] = 15;
    for(int i=0;i<4;i++) sn->phase[i] = 0;
    sn->lfsr = 0x4000;
	sn->output[3] = 0;
	sn->dc = 0;
    sn->lp1 = 0;
    sn->lp2 = 0;
}

static inline void sn_write(SN76489 *sn, uint8_t data)
{
    if(data & 0x80) {
        sn->latched = (data >> 4) & 7;
        int ch = (sn->latched >> 1) & 3;
        if((sn->latched & 1)==0) {
            if(ch < 3) sn->tone[ch] = (sn->tone[ch] & 0x3F0) | (data & 0x0F);
            else {
                sn->noise_mode = (data >> 2) & 1;
                sn->noise_freq = data & 3;
			    sn->lfsr = 0x4000;
			    sn->output[3] = 0;
            }
        } else {
            sn->volume[ch] = data & 0x0F;
        }
    } else {
        int ch = (sn->latched >> 1) & 3;
        if((sn->latched & 1)==0 && ch < 3)
            sn->tone[ch] = (sn->tone[ch] & 0x00F) | ((data & 0x3F) << 4);
    }

    uint64_t base = ((uint64_t)CLOCK_SN << 32) / (32 * SAMPLE_RATE);
    for(int i=0;i<3;i++) {
        uint16_t N = sn->tone[i];
        if(N == 0) { sn->step[i] = 0; continue; }
        if(N < 2) N = 2;
        sn->step[i] = (uint32_t)(base / N);
    }

    switch(sn->noise_freq) {
        case 0: sn->step[3] = (uint32_t)(base / 16); break;
        case 1: sn->step[3] = (uint32_t)(base / 32); break;
        case 2: sn->step[3] = (uint32_t)(base / 64); break;
        case 3: sn->step[3] = sn->step[2]; break;
    }
}

static inline int16_t sn_generate(SN76489 *sn)
{
    int32_t mix = 0;
    for(int i=0;i<3;i++) {
        sn->phase[i] += sn->step[i];
        int32_t s = (sn->phase[i] & 0x80000000) ? 32767 : -32767;
        mix += (s * vol_table[sn->volume[i]]) >> 15;
    }

	// ノイズ生成（完全版）
	uint32_t old = sn->phase[3];
	sn->phase[3] += sn->step[3];

	if((old ^ sn->phase[3]) & 0x80000000) {

	    if(sn->noise_mode == 0) {
	        // ===== 周期ノイズ（ここが重要）=====
	        sn->output[3] ^= 1;   // トグルのみ（LFSR使わない）
	    } else {
	        // ===== ホワイトノイズ =====
	        uint16_t fb = ((sn->lfsr >> 14) ^ (sn->lfsr >> 13)) & 1;
	        sn->lfsr = ((sn->lfsr << 1) | fb) & 0x7FFF;
	        sn->output[3] = sn->lfsr & 1;
	    }
	}
	
	int32_t n = sn->output[3] ? 32767 : -32767;
	int32_t noise = (n * vol_table[sn->volume[3]]) >> 15;
	noise = noise >> 2;   // 強度調整
	mix += noise;
	
    if(mix > 30000) mix = 30000;
    if(mix < -30000) mix = -30000;
    return mix >> 5;
}

#include "hardware/pwm.h"

void sound_task()
{

    static uint32_t last = 0;

    static int32_t dc = 0;
    static int32_t lp1 = 0;
    static int32_t lp2 = 0;

    static int32_t delay = 0;

    uint32_t now = time_us_32();

    while(now - last >= (1000000 / SAMPLE_RATE)) {
        last += (1000000 / SAMPLE_RATE);

        int32_t l = sn_generate(&sn_l);
        int32_t r = sn_generate(&sn_r);

        // ★ 疑似ステレオ
		int32_t pit = i8253_tick();

// SN + PIT ミックス
		int32_t mix = ((l + r) >> 1) + (pit * 3);
        delay = r;

        // DCカット
        dc += (mix - dc) >> 10;
        mix -= dc;

        // 2段ローパス（実機っぽい丸さ）
        lp1 += (mix - lp1) >> 3;
        lp2 += (lp1 - lp2) >> 4;

        int32_t out = lp2;

        if(out < -2048) out = -2048;
        if(out >  2047) out =  2047;

        pwm_set_gpio_level(SOUND_PIN, out + 2048);
    }
}


void sound_init()
{
    gpio_set_function(SOUND_PIN, GPIO_FUNC_PWM);
    pwm_slice_num = pwm_gpio_to_slice_num(SOUND_PIN);
    pwm_config cfg = pwm_get_default_config();
    pwm_config_set_clkdiv(&cfg, 1.0f);
    pwm_config_set_wrap(&cfg, 4095);
    pwm_init(pwm_slice_num, &cfg, true);
}

#define RESET_PIN 25

// RAM configuration
uint8_t __attribute__ ((aligned(4096))) mz1r12[0x8000];
uint8_t __attribute__ ((aligned(4096))) mz1r18[0x10000];
uint8_t __attribute__ ((aligned(4096))) emm[0x50000];

// PCG emulation
uint8_t vram[0x1000];
uint8_t cgram[0x1000];
uint8_t pcg[0x2000 * 3];
uint8_t pcg700[0x800];

volatile uint8_t vram_enabled;
volatile uint8_t pcg_enabled;

#define MAXROMPAGE 64
#define MAXEMMPAGE 32

volatile uint8_t rompage=0;
volatile uint8_t emmpage=0;

volatile uint32_t kanjiptr=0;
volatile uint32_t dictptr=0;
volatile uint32_t kanjictl=0;
volatile uint32_t mz1r18ptr=0;
volatile uint32_t mz1r12ptr=0;
volatile uint32_t emmptr=0;
volatile uint32_t flash_command=0;
volatile uint32_t pcg700_ptr=0;

// ROM configuration
#define ROMBASE 0x10080000u

uint8_t *fontrom=(uint8_t *)(ROMBASE-0x61000);
uint8_t *kanjirom=(uint8_t *)(ROMBASE-0x60000);
uint8_t *jishorom=(uint8_t *)(ROMBASE-0x40000);
uint8_t *romslots=(uint8_t *)(ROMBASE);
uint8_t *emmslots=(uint8_t *)(ROMBASE+(0x8000*MAXROMPAGE));

// ======================================================
// サウンドハンドラ (HSYNC 割り込み内で呼び出し)
// ======================================================
volatile uint32_t sound_tick = 0;
uint16_t psg_master_volume = 0;

// VGA Output
uint8_t scandata[320];
extern unsigned char vga_data_array[];
volatile uint32_t video_hsync,video_vsync,scanline,vsync_scanline;
volatile uint8_t pcg_control;
volatile uint8_t pcg700_control,pcg700_data;
uint8_t pallet[8];

void __not_in_flash_func(mzscan)(uint8_t scan);

// ========== 修正: hsync_handler 内のタイマ割り込み処理 ==========
void __not_in_flash_func(hsync_handler)(void)
{

	pio_interrupt_clear(pio0, 0);

    if((scanline!=0) && (gpio_get(VSYNC)==0)) {
        scanline=0;
        video_vsync=1;
    } else {
        scanline++;
    }

    if((scanline%2)==0) {
        video_hsync=1;
        if((scanline>=73) && (scanline<=472)) {
            uint32_t tmsscan = (scanline-73)/2;
            uint32_t vramindex = (tmsscan%4)*320;
            mzscan(tmsscan);
            for(int j=0;j<320;j++) vga_data_array[vramindex+j] = scandata[j];
        }
    }

    // i8253 チャンネル1 (15.75kHz クロック)
    if((i8253_access[1]<2) && (i8253_preload[1]!=0)) {
        if(i8253_counter[1] > 1) {
            i8253_counter[1]--;
            if(i8253_counter[1] == 1) {
                // チャンネル2 をデクリメント
                if((i8253_access[2]<2) && (i8253_preload[2]!=0)) {
                    if(i8253_pending[2]) {
                        i8253_pending[2] = 0;
                    } else {
                        if(i8253_counter[2] > 1) {
                            i8253_counter[2]--;
                        } else {
                            // カウンタが0になったら割り込み発生 (ワンショット)
                            if(memioport[2] & 0x04) {
                                i8253_enable_irq = 2;
                            }
                            // PIO 割り込み条件をチェック (ビット5 = タイマ割り込み)
                            if((pioa[2] & 0x80) && ((pioa[3] & 0x20) == 0)) {
                                pioa_enable_irq = 1;
                                pioa_data |= 0x20;
                            }
                            // モード0: カウンタを停止 (リロードしない)
                        }
                    }
                }
            }
        } else {
            i8253_counter[1] = i8253_preload[1];
        }
    }
}

// ========== PIOA データ読み出し (割り込みフラグクリア) ==========
static inline uint8_t pioa_read(void)
{
    uint8_t ret = pioa_data;
    pioa_data &= ~0x30;   // ビット4,5 クリア
    return ret;
}

// ========== I/O 書き込み (PIO 完全実装) ==========
static inline void io_write(uint16_t address, uint8_t data)
{
    uint8_t b;

    switch(address & 0xFF) {
        case 0xb8: kanjictl = data; return;
        case 0xb9: dictptr = data + (address & 0xFF00); kanjiptr = dictptr << 5; return;
        case 0xea: mz1r18[mz1r18ptr & 0xFFFF] = data; mz1r18ptr++; return;
        case 0xeb: mz1r18ptr = data + (address & 0xFF00); return;
        case 0xf8: mz1r12ptr = (data << 8) + (mz1r12ptr & 0xFF); mz1r12ptr &= 0x7FFF; return;
        case 0xf9: mz1r12ptr = data + (mz1r12ptr & 0xFF00); return;
        case 0xfa: mz1r12[mz1r12ptr & 0x7FFF] = data; mz1r12ptr++; if(mz1r12ptr > 0x7FFF) mz1r12ptr = 0; return;
        case 0xba: rompage = data & 0x3F; flash_command = 0x10000000 + (data & 0x3F); return;
        case 0xbb: rompage = data & 0x3F; flash_command = 0x20000000 + (data & 0x3F); return;
        case 0xbc: emmpage = data & 0x1F; flash_command = 0x30000000 + (data & 0x1F); return;
        case 0xbd: emmpage = data & 0x1F; flash_command = 0x40000000 + (data & 0x1F); return;
        case 0x00: emmptr = (emmptr & 0x7FF00) + data; return;
        case 0x01: emmptr = (emmptr & 0x700FF) + (data << 8); return;
        case 0x02: emmptr = (emmptr & 0xFFFF) + ((data & 7) << 16); return;
        case 0x03: if(emmptr > 0x4FFFF) emmptr -= 0x50000; emm[emmptr++] = data; return;
        case 0xe1: vram_enabled = 0; return;
        case 0xe3: vram_enabled = 1; return;
        case 0xe4: vram_enabled = 1; pcg_enabled = 0xFF; return;
        case 0xe5: pcg_enabled = data & 3; return;
        case 0xe6: pcg_enabled = 0xFF; return;
        case 0xf0: pcg_control = data; return;
        case 0xf1: pallet[(data & 0x70) >> 4] = data & 7; return;
        case 0xf2: sn_write(&sn_l, data); return;
        case 0xf3: sn_write(&sn_r, data); return;
        case 0xe9: sn_write(&sn_l, data); sn_write(&sn_r, data); return;

        // ===== PIOA (アドレス 0xFC) =====
        case 0xfc:
            if(pioa_next_mask) {
                pioa[3] = data;          // マスクレジスタ
                pioa_next_mask = 0;
                return;
            }
            if(pioa_next_iocontrol) {
                pioa_next_iocontrol = 0;
                return;
            }
            switch(data & 0x0F) {
                case 0x00: case 0x02: case 0x04: case 0x08:
                case 0x0A: case 0x0C: case 0x0E:
                    pioa[0] = data;       // コントロールワード
                    return;
                case 0x03: // 割り込み許可/禁止
                    if(data & 0x80) pioa[2] |= 0x80;
                    else pioa[2] &= 0x7F;
                    return;
                case 0x07: // 割り込み制御
                    pioa[2] = data;
                    if(data & 0x10) pioa_next_mask = 1;
                    return;
                case 0x0F: // モード制御
                    if((data & 0xC0) == 0xC0) pioa_next_iocontrol = 1;
                    return;
                default: return;
            }
            break;

        // ===== PIOB (アドレス 0xFD) は未使用なので簡易実装 =====
        case 0xfd:
            // 必要に応じて実装 (今回はダミー)
            return;

        // ===== PIOA データ書き込み (アドレス 0xFE) =====
        case 0xfe:
            pioa_data = data;
            pioa_data &= 0xCF;   // ビット4,5 は読み出し専用
            return;
    }
}

// ========== メモリ書き込み (元のまま) ==========
static inline void memory_write(uint16_t address, uint8_t data)
{
    if(address < 0xD000) return; // Main RAM は無視

    if((pcg_enabled != 0xFF) && (address < 0xF000)) {
        if((pcg_enabled & 3) != 0) {
            pcg[(address - 0xD000) + ((pcg_enabled & 3) - 1) * 0x2000] = data;
        }
    } else if(vram_enabled && (address < 0xE000)) {
        vram[address & 0xFFF] = data;
    } else if(vram_enabled && (address >= 0xE800)) {
//        mz1r12[address - 0xE800] = data;
    } else if(vram_enabled) {
        switch(address) {
            case 0xE002: // i8255 ポートC
                if(data & 1) beep_mute = 0; else beep_mute = 1;
                if(data & 4) i8253_enable_irq = 1; else i8253_enable_irq = 0;
                memioport[2] = data;
                return;
            case 0xE003: // i8255 ポートC ビット操作
                if((data & 0x80) == 0) {
                    uint8_t b = (data & 0x0E) >> 1;
                    if(data & 1) memioport[2] |= (1 << b);
                    else memioport[2] &= ~(1 << b);
                }
                return;
            case 0xE004: case 0xE005: case 0xE006: { // i8253 チャンネル0-2
                int ch = address - 0xE004;
                if((i8253[ch] & 0x30) == 0x30) {
                    if(i8253_access[ch]) {
                        i8253_preload[ch] = (i8253_preload[ch] & 0xFF) | (data << 8);
                        i8253_access[ch] = 0;
                        i8253_counter[ch] = i8253_preload[ch];
                    } else {
                        i8253_preload[ch] = (i8253_preload[ch] & 0xFF00) | data;
                        i8253_access[ch] = 2;
                    }
                }
                if((i8253[ch] & 0x30) == 0x20) {
                    i8253_preload[ch] = (data << 8);
                    i8253_counter[ch] = i8253_preload[ch];
                }
                if((i8253[ch] & 0x30) == 0x10) {
                    i8253_preload[ch] = data;
                    i8253_counter[ch] = i8253_preload[ch];
                }
                i8253_pending[ch] = 1;
                return;
            }
            case 0xE007: { // i8253 コントロール
                uint8_t b = (data & 0xC0) >> 6;
                if(b != 3) {
                    if((data & 0x30) == 0) {
                        i8253_latch[b] = i8253_counter[b];
                        i8253_latch_flag = 1;
                    }
                    i8253[b] = data;
                }
                return;
            }
            case 0xE008: // Beep 制御
                if(data & 1) beep_flag = 1; else beep_flag = 0;
                memioport[8] = data;
                return;
            case 0xE010: pcg700_data = data; return;
            case 0xE011: pcg700_ptr &= 0x700; pcg700_ptr |= data; return;
            case 0xE012:
                if(pcg700_control & 0x10) {
                    if((data & 0x10) == 0) {
                        if(pcg700_control & 0x20) {
                            if(pcg700_ptr < 0x400) pcg700[pcg700_ptr] = cgram[pcg700_ptr + 0x400];
                            else pcg700[pcg700_ptr] = cgram[pcg700_ptr + 0x800];
                        } else {
                            pcg700[pcg700_ptr] = pcg700_data;
                        }
                    }
                } else {
                    if(data & 0x10) {
                        pcg700_ptr &= 0xFF;
                        pcg700_ptr |= (data & 7) << 8;
                    }
                }
                pcg700_control = data;
                return;
        }
    }
}

// ========== リセット処理 ==========
void __not_in_flash_func(z80reset)(uint gpio, uint32_t event)
{
    gpio_acknowledge_irq(RESET_PIN, GPIO_IRQ_EDGE_RISE);
    if(gpio_get(RESET_PIN) == 0) return;

    kanjiptr = 0;
    dictptr = 0;
    kanjictl = 0;
    mz1r18ptr = 0;
    mz1r12ptr = 0;
    emmptr = 0;
    pcg_control = 0;
    pcg700_ptr = 0;
    pcg700_control = 0xFF;
    vram_enabled = 1;
    pcg_enabled = 0xFF;

    memset((void*)i8253, 0, sizeof(i8253));
    memset((void*)i8253_counter, 0, sizeof(i8253_counter));
    memset((void*)i8253_preload, 0, sizeof(i8253_preload));
    memset((void*)i8253_access, 0, sizeof(i8253_access));

    sound_init();
    sn_reset(&sn_l);
    sn_reset(&sn_r);
}
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
int main()
{
    vreg_set_voltage(VREG_VOLTAGE_1_20);
    set_sys_clock_khz(300000, true);
    initVGA();

	    // ★ サウンド初期化を追加
    sound_init();
    sn_reset(&sn_l);
    sn_reset(&sn_r);

	
	multicore_launch_core1(main_core1);
    init_emulator();

    irq_set_exclusive_handler(PIO0_IRQ_0, hsync_handler);
    irq_set_enabled(PIO0_IRQ_0, true);
    pio_set_irq0_source_enabled(pio0, pis_interrupt0, true);

    gpio_set_irq_enabled_with_callback(RESET_PIN, GPIO_IRQ_EDGE_RISE, true, z80reset);

    while(1) {

    sound_task();
    	
        if(flash_command) {
            switch(flash_command & 0xF0000000) {
                case 0x10000000: memcpy(mz1r12, romslots + (flash_command & 0x3F) * 0x8000, 0x8000); break;
                case 0x20000000:
                    for(uint32_t i = 0; i < 0x8000; i += 4096) {
                        uint32_t ints = save_and_disable_interrupts();
                        flash_range_erase(i + 0x80000 + (flash_command & 0x3F) * 0x8000, 4096);
                        restore_interrupts(ints);
                    }
                    for(uint32_t i = 0; i < 0x8000; i += 4096) {
                        uint32_t ints = save_and_disable_interrupts();
                        flash_range_program(i + 0x80000 + (flash_command & 0x3F) * 0x8000, (const uint8_t *)(mz1r12 + i), 4096);
                        restore_interrupts(ints);
                    }
                    break;
                case 0x30000000: memcpy(emm, emmslots + (flash_command & 0x1F) * 0x50000, 0x50000); break;
                case 0x40000000:
                    for(uint32_t i = 0; i < 0x50000; i += 4096) {
                        uint32_t ints = save_and_disable_interrupts();
                        flash_range_erase(i + 0x280000 + (flash_command & 0x1F) * 0x50000, 4096);
                        restore_interrupts(ints);
                    }
                    for(uint32_t i = 0; i < 0x50000; i += 4096) {
                        uint32_t ints = save_and_disable_interrupts();
                        flash_range_program(i + 0x280000 + (flash_command & 0x1F) * 0x50000, (const uint8_t *)(emm + i), 4096);
                        restore_interrupts(ints);
                    }
                    break;
            }
            flash_command = 0;
        }

        // EXINT 制御 (割り込み要求があれば Low にする)
        if(pioa_enable_irq) {
            gpio_put(24, false);
        }
    }
}
